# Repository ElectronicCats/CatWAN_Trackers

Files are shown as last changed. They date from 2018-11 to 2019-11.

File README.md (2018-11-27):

# LoRa CatTrack Zero

Electronic Cats invests time and resources providing this open source design, please support Electronic Cats and open-source hardware by purchasing products from Electronic Cats!

Designed by Electronic Cats.

Hardware released under an CERN Open Hardware Licence v1.2. See the LICENSE_HARDWARE file for more information.

Electronic Cats is a registered trademark, please do not use if you sell these PCBs.

26 Nov 2018

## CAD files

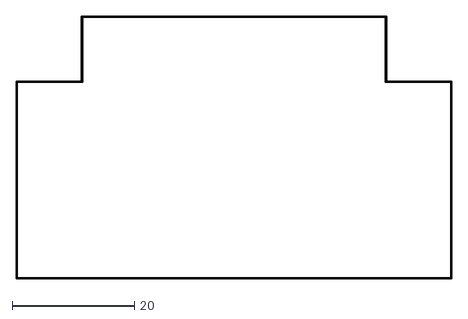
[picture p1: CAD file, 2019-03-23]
Hardware/gps_minimo/gps_vehicular-Edge_Cuts.dxf
71.3 x 43.1

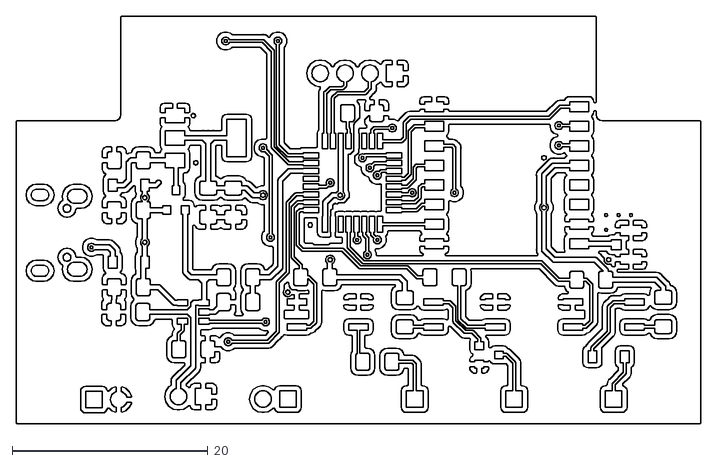
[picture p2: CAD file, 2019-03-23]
Hardware/gps_minimo/gps_vehicular-F_Cu.dxf
69.9 x 41.6

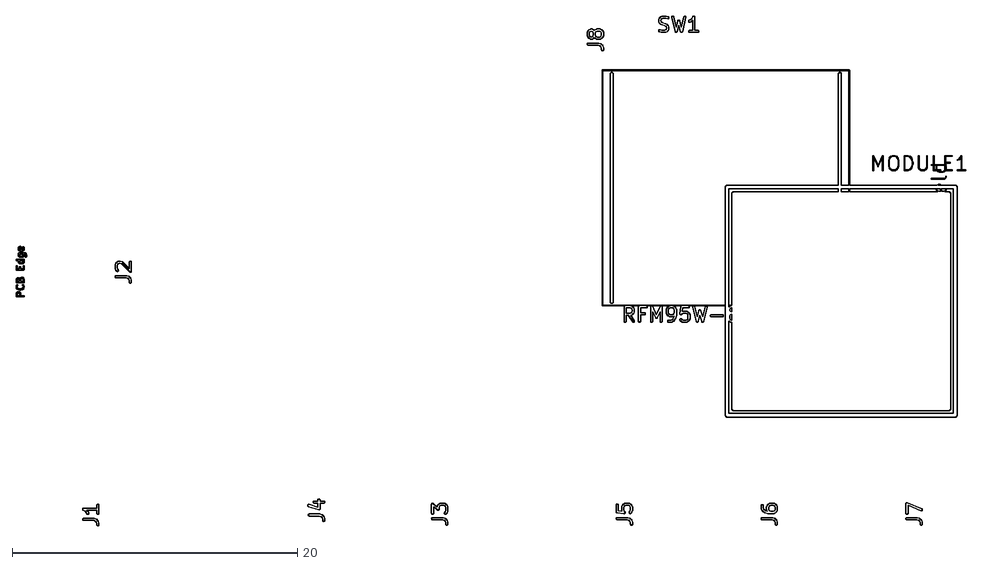
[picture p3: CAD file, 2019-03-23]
Hardware/gps_minimo/gps_vehicular-Dwgs_User.dxf
66.6 x 35.8

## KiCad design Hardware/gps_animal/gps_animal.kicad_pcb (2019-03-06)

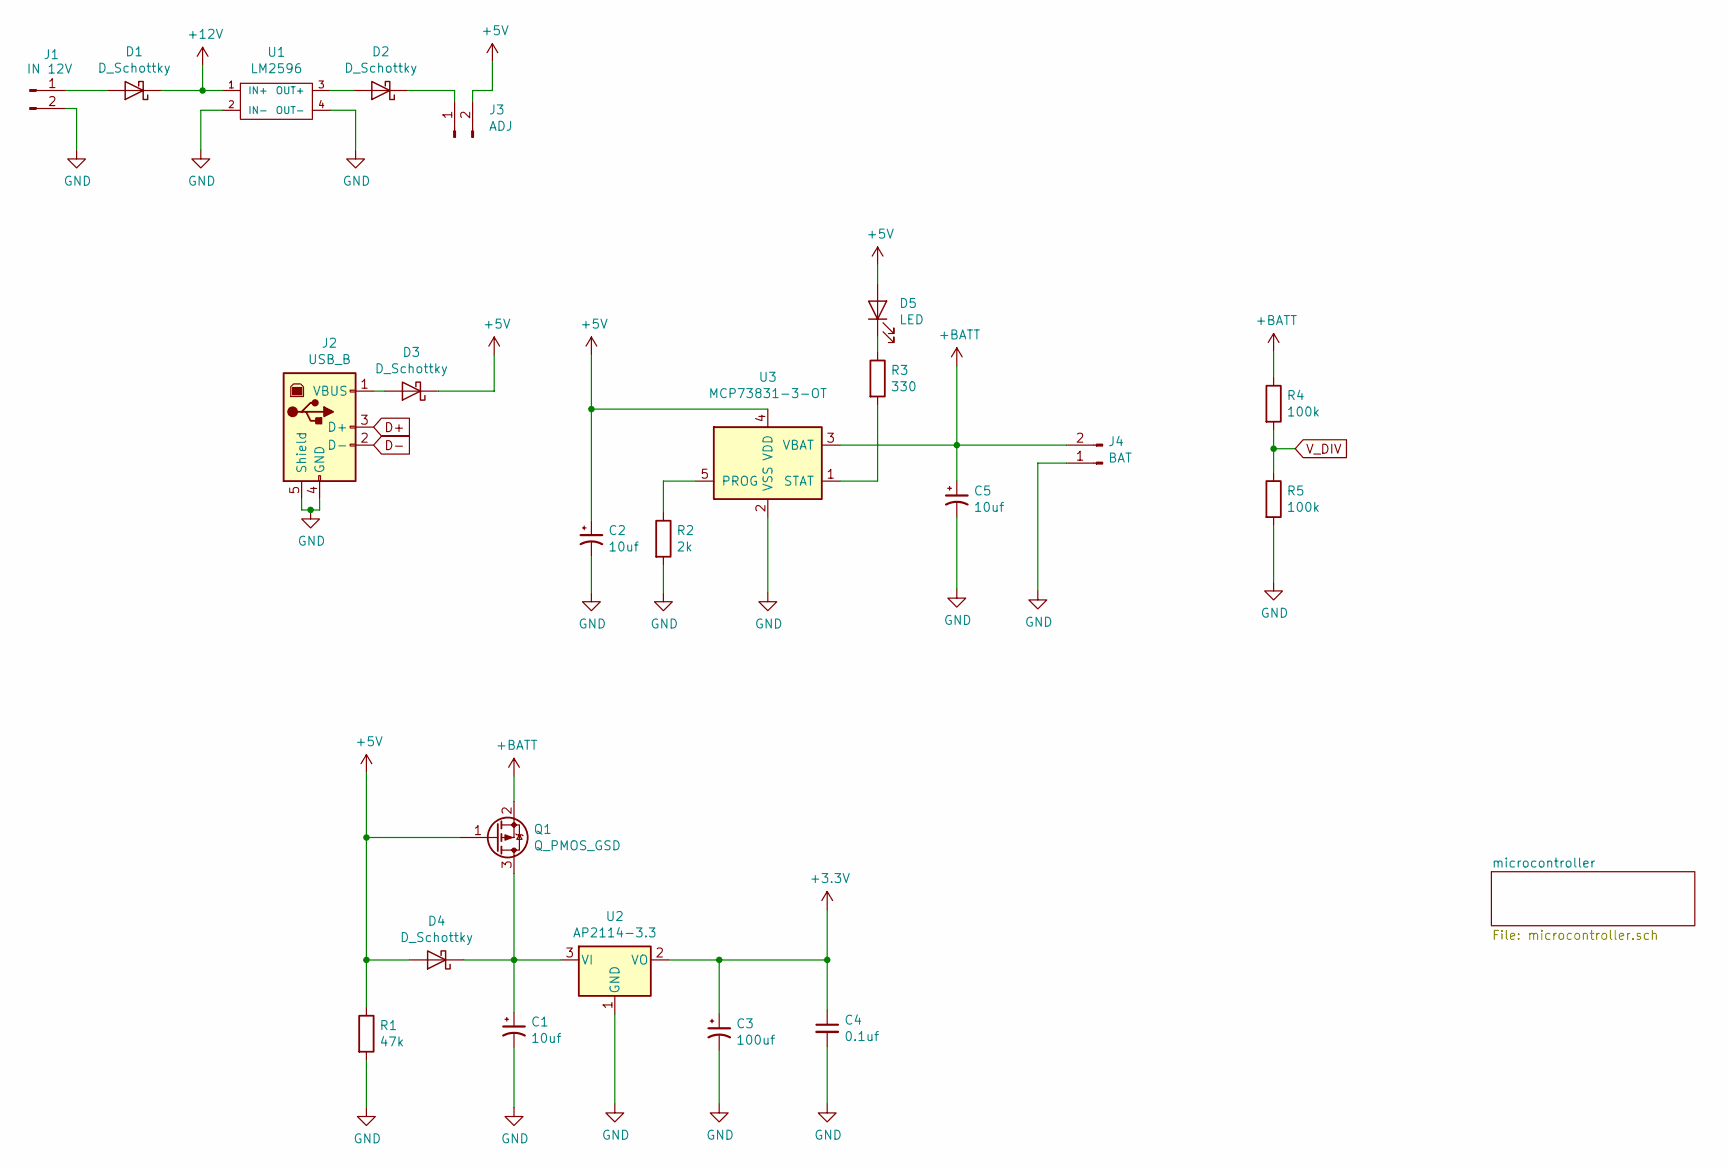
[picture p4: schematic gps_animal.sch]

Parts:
C1, C2, C5: 10uf; C_1206_3216Metric_Pad1.42x1.75mm_HandSolder
C3: 100uf; C_1206_3216Metric_Pad1.42x1.75mm_HandSolder
C4: 0.1uf; C_1206_3216Metric_Pad1.42x1.75mm_HandSolder
D1, D2, D3, D4: D_Schottky; D_SOD-123
D5: LED; LED_1206_3216Metric_Pad1.42x1.75mm_HandSolder
J1: IN 12V; PinHeader_1x02_P2.54mm_Vertical
J2: USB_B; USB_Micro-B_Wuerth_629105150521
J3: ADJ; PinHeader_1x02_P2.54mm_Vertical
J4: BAT; PinHeader_1x02_P2.54mm_Vertical
Q1: Q_PMOS_GSD; SOT-23
R1: 47k; R_1206_3216Metric_Pad1.42x1.75mm_HandSolder
R2: 2k; R_1206_3216Metric_Pad1.42x1.75mm_HandSolder
R3: 330; R_1206_3216Metric_Pad1.42x1.75mm_HandSolder
R4, R5: 100k; R_1206_3216Metric_Pad1.42x1.75mm_HandSolder
U1: LM2596; LM2596DC-DC
U2: AP2114-3.3; SOT-223-3_TabPin2
U3: MCP73831-3-OT; SOT-23-5

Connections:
+3V3: C3.1, C4.1, U2.2 (VO); also elsewhere on the board
+5V: C2.1, D3.1 (K), D4.2 (A), D5.2 (A), J3.2, Q1.1 (G), R1.1, U3.4 (VDD)
+12V: D1.1 (K), U1.1 (IN+); also elsewhere on the board
+BATT: C5.1, J4.2, Q1.2 (S), R4.1, U3.3 (VBAT)
D+: J2.3 (D+); also elsewhere on the board
D-: J2.2 (D-); also elsewhere on the board
GND: C1.2, C2.2, C3.2, C4.2, C5.2, J1.2, J2.4 (GND), J2.5 (Shield), J4.1, R1.2, R2.2, R5.2, U1.2 (IN-), U1.4 (OUT-), U2.1 (GND), U3.2 (VSS); also elsewhere on the board
unnamed: C1.1, D4.1 (K), Q1.3 (D), U2.3 (VI)
unnamed: D1.2 (A), J1.1
unnamed: D2.1 (K), J3.1
unnamed: D2.2 (A), U1.3 (OUT+)
unnamed: D3.2 (A), J2.1 (VBUS)
unnamed: D5.1 (K), R3.1
unnamed: R2.1, U3.5 (PROG)
unnamed: R3.2, U3.1 (STAT)
V_DIV: R4.2, R5.1

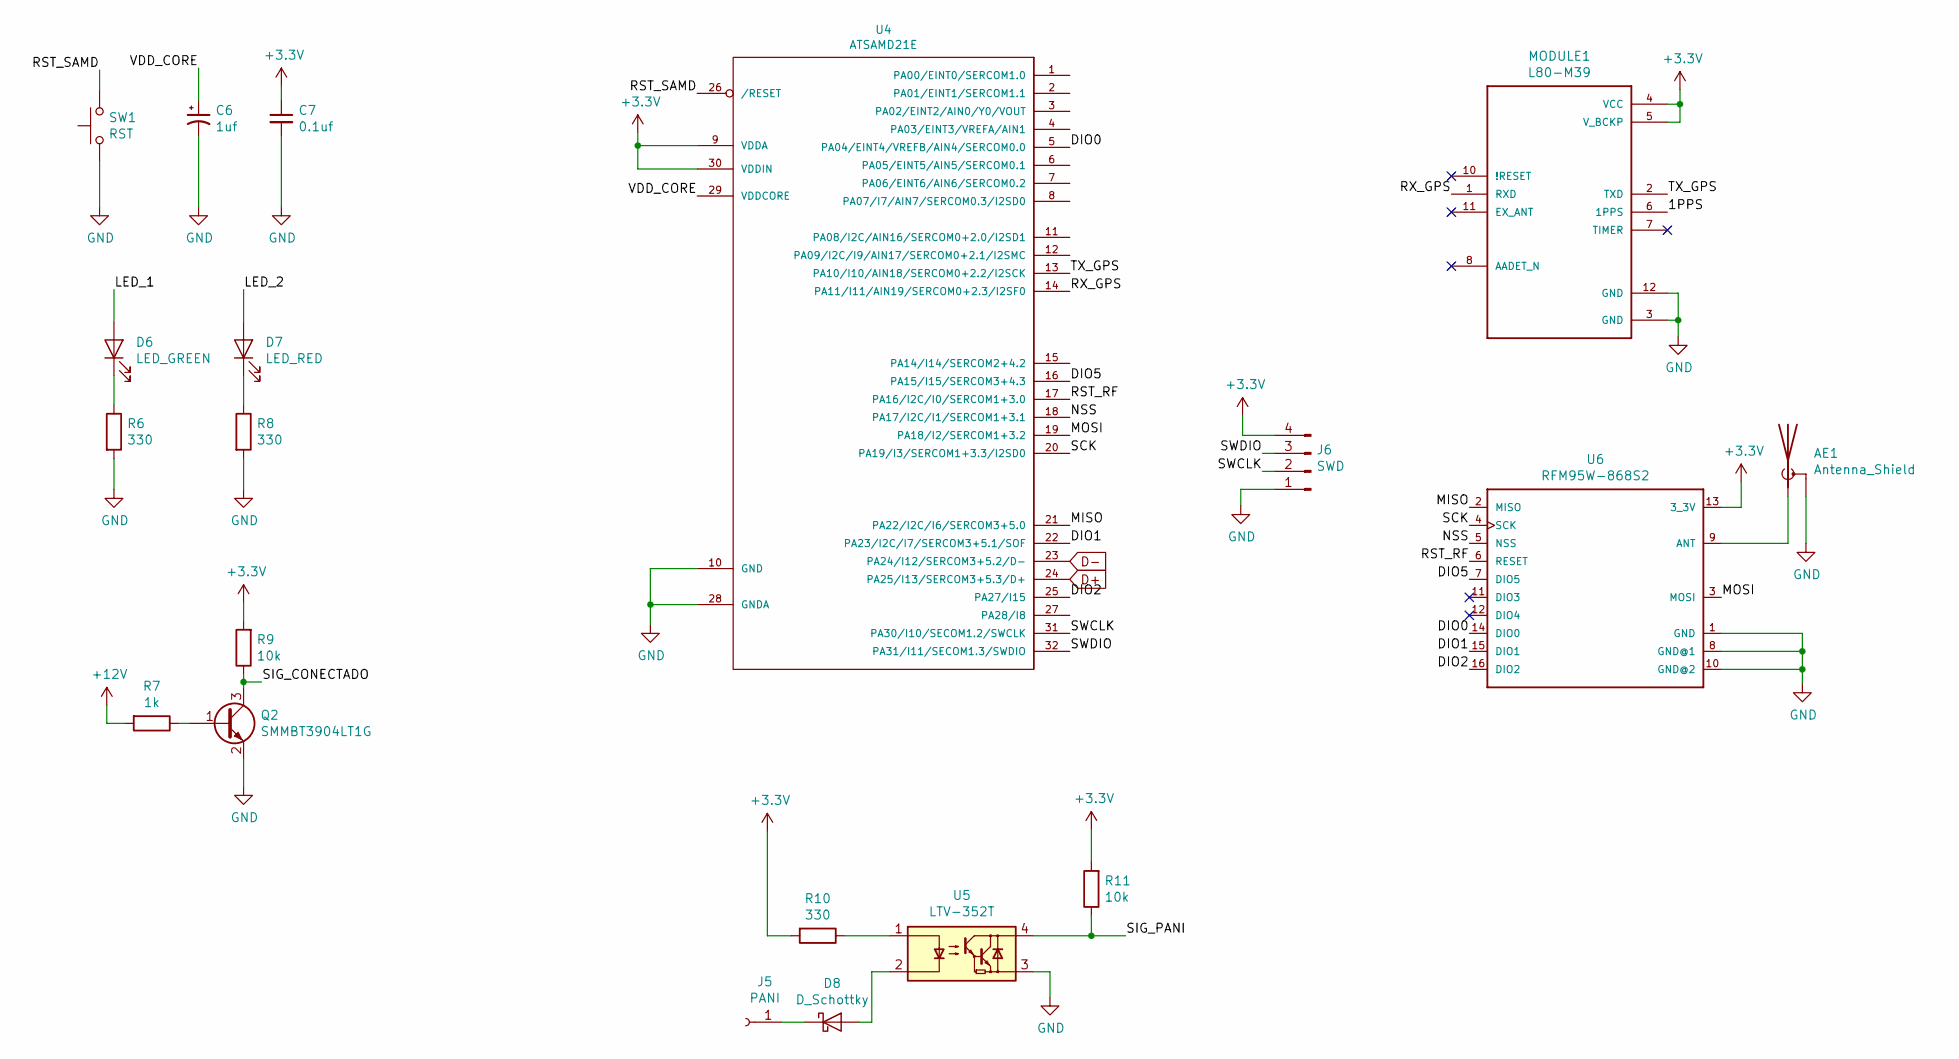
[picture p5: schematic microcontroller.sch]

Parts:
AE1: Antenna_Shield; MOLEX_1661
C6: 1uf; C_1206_3216Metric_Pad1.42x1.75mm_HandSolder
C7: 0.1uf; C_1206_3216Metric_Pad1.42x1.75mm_HandSolder
D6: LED_GREEN; LED_1206_3216Metric_Castellated
D7: LED_RED; LED_1206_3216Metric_Castellated
D8: D_Schottky; D_SOD-123
J5: PANI; PinHeader_1x01_P2.54mm_Vertical
J6: SWD; PinHeader_1x04_P2.54mm_Vertical
MODULE1: L80-M39; QUECTEL_L80-M39
Q2: SMMBT3904LT1G; SOT-23
R6, R8, R10: 330; R_1206_3216Metric_Pad1.42x1.75mm_HandSolder
R7: 1k; R_1206_3216Metric_Pad1.42x1.75mm_HandSolder
R9, R11: 10k; R_1206_3216Metric_Pad1.42x1.75mm_HandSolder
SW1: RST; SW_SPST_TL3342
U4: ATSAMD21E; TQFP-32_7x7mm_P0.8mm
U5: LTV-352T; SO-4_4.4x3.6mm_P2.54mm
U6: RFM95W-868S2; RFM95W

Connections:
+3V3: C7.1, J6.4, MODULE1.4 (VCC), MODULE1.5 (V_BCKP), R9.2, R10.2, R11.2, U4.9 (VDDA), U4.30 (VDDIN), U6.13 (3_3V); also elsewhere on the board
+12V: R7.2; also elsewhere on the board
/microcontroller/1PPS: MODULE1.6 (1PPS)
/microcontroller/DIO0: U4.5 (PA04/EINT4/VREFB/AIN4/SERCOM0.0), U6.14 (DIO0)
/microcontroller/DIO1: U4.22 (PA23/I2C/I7/SERCOM3+5.1/SOF), U6.15 (DIO1)
/microcontroller/DIO2: U4.25 (PA27/I15), U6.16 (DIO2)
/microcontroller/DIO5: U4.16 (PA15/I15/SERCOM3+4.3), U6.7 (DIO5)
/microcontroller/LED_1: D6.2 (A)
/microcontroller/LED_2: D7.2 (A)
/microcontroller/MISO: U4.21 (PA22/I2C/I6/SERCOM3+5.0), U6.2 (MISO)
/microcontroller/MOSI: U4.19 (PA18/I2/SERCOM1+3.2), U6.3 (MOSI)
/microcontroller/NSS: U4.18 (PA17/I2C/I1/SERCOM1+3.1), U6.5 (NSS)
/microcontroller/RST_RF: U4.17 (PA16/I2C/I0/SERCOM1+3.0), U6.6 (RESET)
/microcontroller/RST_SAMD: SW1.2, U4.26 (/RESET)
/microcontroller/RX_GPS: MODULE1.1 (RXD), U4.14 (PA11/I11/AIN19/SERCOM0+2.3/I2SF0)
/microcontroller/SCK: U4.20 (PA19/I3/SERCOM1+3.3/I2SD0), U6.4 (SCK)
/microcontroller/SIG_CONECTADO: Q2.3 (C), R9.1
/microcontroller/SIG_PANI: R11.1, U5.4
/microcontroller/SWCLK: J6.2, U4.31 (PA30/I10/SECOM1.2/SWCLK)
/microcontroller/SWDIO: J6.3, U4.32 (PA31/I11/SECOM1.3/SWDIO)
/microcontroller/TX_GPS: MODULE1.2 (TXD), U4.13 (PA10/I10/AIN18/SERCOM0+2.2/I2SCK)
/microcontroller/VDD_CORE: C6.1, U4.29 (VDDCORE)
D+: U4.24 (PA25/I13/SERCOM3+5.3/D+); also elsewhere on the board
D-: U4.23 (PA24/I12/SERCOM3+5.2/D-); also elsewhere on the board
GND: AE1.2 (Shield), C6.2, C7.2, J6.1, MODULE1.3 (GND), MODULE1.12 (GND), Q2.2 (E), R6.2, R8.2, SW1.1, U4.10 (GND), U4.28 (GNDA), U5.3, U6.1 (GND), U6.8 (GND@1), U6.10 (GND@2); also elsewhere on the board
unnamed: AE1.1 (A), U6.9 (ANT)
unnamed: D6.1 (K), R6.1
unnamed: D7.1 (K), R8.1
unnamed: D8.1 (K), J5.1
unnamed: D8.2 (A), U5.2
unnamed: Q2.1 (B), R7.1
unnamed: R10.1, U5.1

Board: 2 copper layers, 43 parts (0 on the bottom side), 40 nets, no tracks yet.

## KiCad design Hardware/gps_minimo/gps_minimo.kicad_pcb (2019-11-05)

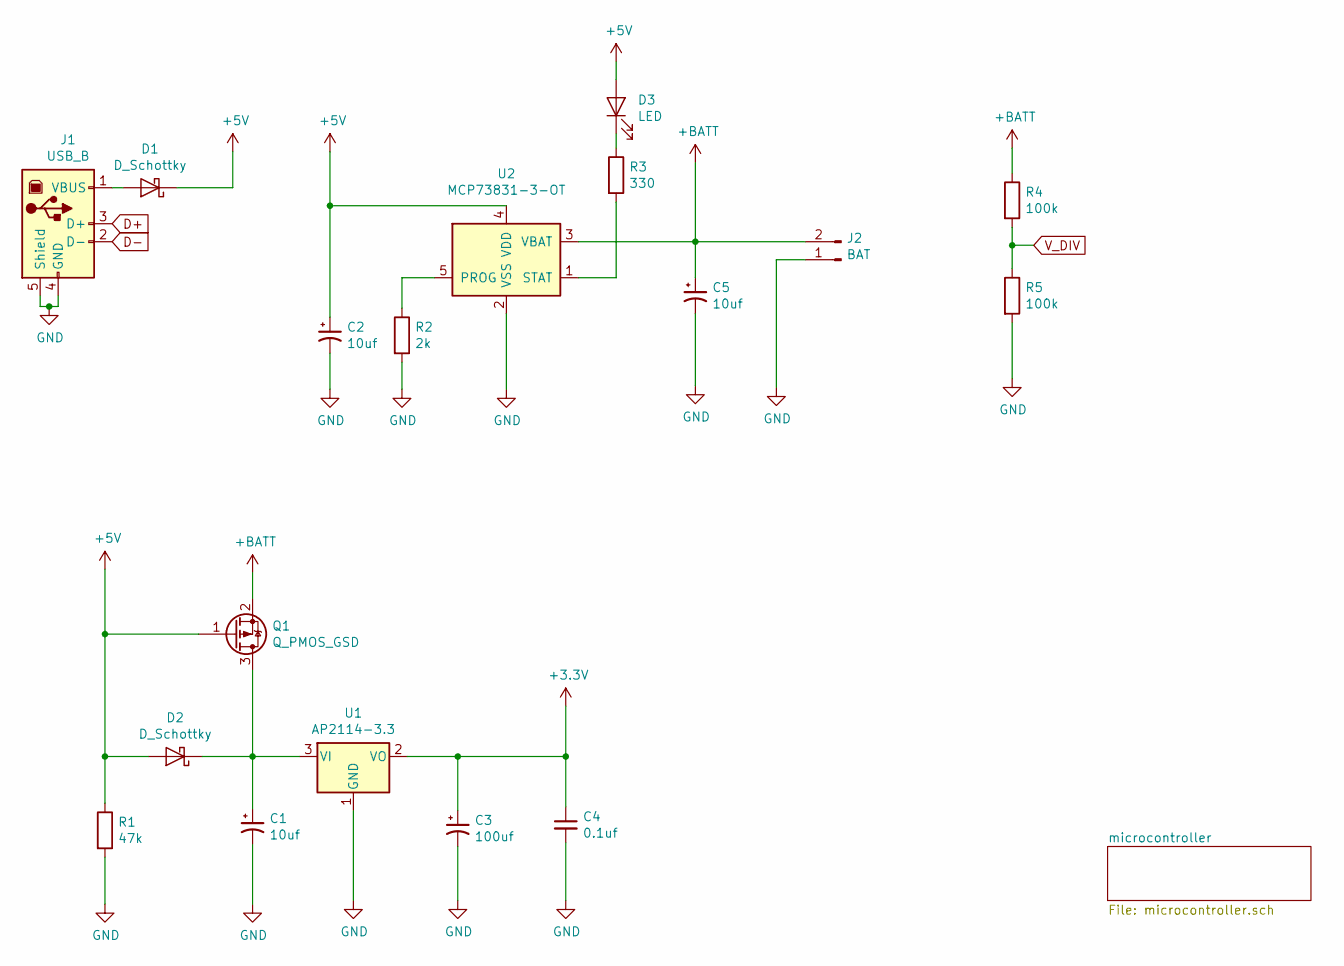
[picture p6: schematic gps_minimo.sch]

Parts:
C1, C2, C5: 10uf; C_1206_3216Metric_Pad1.42x1.75mm_HandSolder
C3: 100uf; C_1206_3216Metric_Pad1.42x1.75mm_HandSolder
C4: 0.1uf; C_1206_3216Metric_Pad1.42x1.75mm_HandSolder
D1, D2: D_Schottky; D_SOD-123
D3: LED; LED_1206_3216Metric_Pad1.42x1.75mm_HandSolder
J1: USB_B; USB_Micro-B_Wuerth_629105150521
J2: BAT; PinHeader_1x02_P2.54mm_Vertical
Q1: Q_PMOS_GSD; SOT-23
R1: 47k; R_1206_3216Metric_Pad1.42x1.75mm_HandSolder
R2: 2k; R_1206_3216Metric_Pad1.42x1.75mm_HandSolder
R3: 330; R_1206_3216Metric_Pad1.42x1.75mm_HandSolder
R4, R5: 100k; R_1206_3216Metric_Pad1.42x1.75mm_HandSolder
U1: AP2114-3.3; SOT-223-3_TabPin2
U2: MCP73831-3-OT; SOT-23-5

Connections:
+3V3: C3.1, C4.1, U1.2 (VO); also elsewhere on the board
+5V: C2.1, D1.1 (K), D2.2 (A), D3.2 (A), Q1.1 (G), R1.1, U2.4 (VDD)
+BATT: C5.1, J2.2, Q1.2 (S), R4.1, U2.3 (VBAT)
D+: J1.3 (D+); also elsewhere on the board
D-: J1.2 (D-); also elsewhere on the board
GND: C1.2, C2.2, C3.2, C4.2, C5.2, J1.4 (GND), J1.5 (Shield), J2.1, R1.2, R2.2, R5.2, U1.1 (GND), U2.2 (VSS); also elsewhere on the board
unnamed: C1.1, D2.1 (K), Q1.3 (D), U1.3 (VI)
unnamed: D1.2 (A), J1.1 (VBUS)
unnamed: D3.1 (K), R3.1
unnamed: R2.1, U2.5 (PROG)
unnamed: R3.2, U2.1 (STAT)
V_DIV: R4.2, R5.1; also elsewhere on the board

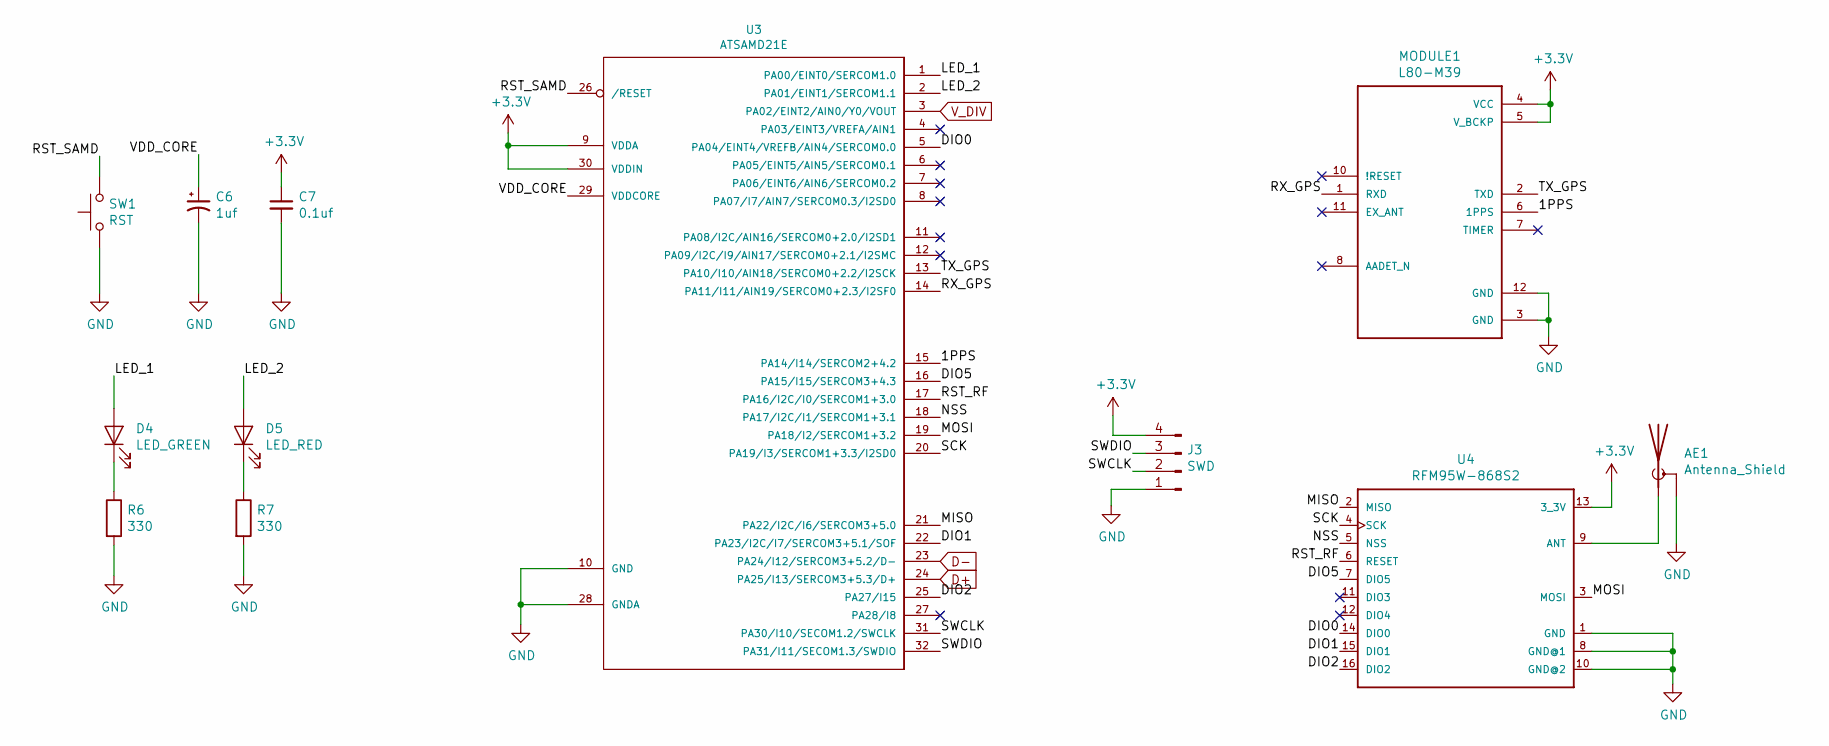
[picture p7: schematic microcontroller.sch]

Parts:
AE1: Antenna_Shield; MOLEX_1661
C6: 1uf; C_1206_3216Metric_Pad1.42x1.75mm_HandSolder
C7: 0.1uf; C_1206_3216Metric_Pad1.42x1.75mm_HandSolder
D4: LED_GREEN; LED_1206_3216Metric_Castellated
D5: LED_RED; LED_1206_3216Metric_Castellated
J3: SWD; PinHeader_1x04_P2.54mm_Vertical
MODULE1: L80-M39; QUECTEL_L80-M39
R6, R7: 330; R_1206_3216Metric_Pad1.42x1.75mm_HandSolder
SW1: RST; SW_SPST_TL3342
U3: ATSAMD21E; TQFP-32_7x7mm_P0.8mm
U4: RFM95W-868S2; RFM95W

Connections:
+3V3: C7.1, J3.4, MODULE1.4 (VCC), MODULE1.5 (V_BCKP), U3.9 (VDDA), U3.30 (VDDIN), U4.13 (3_3V); also elsewhere on the board
/microcontroller/1PPS: MODULE1.6 (1PPS), U3.15 (PA14/I14/SERCOM2+4.2)
/microcontroller/DIO0: U3.5 (PA04/EINT4/VREFB/AIN4/SERCOM0.0), U4.14 (DIO0)
/microcontroller/DIO1: U3.22 (PA23/I2C/I7/SERCOM3+5.1/SOF), U4.15 (DIO1)
/microcontroller/DIO2: U3.25 (PA27/I15), U4.16 (DIO2)
/microcontroller/DIO5: U3.16 (PA15/I15/SERCOM3+4.3), U4.7 (DIO5)
/microcontroller/LED_1: D4.2 (A), U3.1 (PA00/EINT0/SERCOM1.0)
/microcontroller/LED_2: D5.2 (A), U3.2 (PA01/EINT1/SERCOM1.1)
/microcontroller/MISO: U3.21 (PA22/I2C/I6/SERCOM3+5.0), U4.2 (MISO)
/microcontroller/MOSI: U3.19 (PA18/I2/SERCOM1+3.2), U4.3 (MOSI)
/microcontroller/NSS: U3.18 (PA17/I2C/I1/SERCOM1+3.1), U4.5 (NSS)
/microcontroller/RST_RF: U3.17 (PA16/I2C/I0/SERCOM1+3.0), U4.6 (RESET)
/microcontroller/RST_SAMD: SW1.2, U3.26 (/RESET)
/microcontroller/RX_GPS: MODULE1.1 (RXD), U3.14 (PA11/I11/AIN19/SERCOM0+2.3/I2SF0)
/microcontroller/SCK: U3.20 (PA19/I3/SERCOM1+3.3/I2SD0), U4.4 (SCK)
/microcontroller/SWCLK: J3.2, U3.31 (PA30/I10/SECOM1.2/SWCLK)
/microcontroller/SWDIO: J3.3, U3.32 (PA31/I11/SECOM1.3/SWDIO)
/microcontroller/TX_GPS: MODULE1.2 (TXD), U3.13 (PA10/I10/AIN18/SERCOM0+2.2/I2SCK)
/microcontroller/VDD_CORE: C6.1, U3.29 (VDDCORE)
D+: U3.24 (PA25/I13/SERCOM3+5.3/D+); also elsewhere on the board
D-: U3.23 (PA24/I12/SERCOM3+5.2/D-); also elsewhere on the board
GND: AE1.2 (Shield), C6.2, C7.2, J3.1, MODULE1.3 (GND), MODULE1.12 (GND), R6.2, R7.2, SW1.1, U3.10 (GND), U3.28 (GNDA), U4.1 (GND), U4.8 (GND@1), U4.10 (GND@2); also elsewhere on the board
unnamed: AE1.1 (A), U4.9 (ANT)
unnamed: D4.1 (K), R6.1
unnamed: D5.1 (K), R7.1
V_DIV: U3.3 (PA02/EINT2/AIN0/Y0/VOUT); also elsewhere on the board

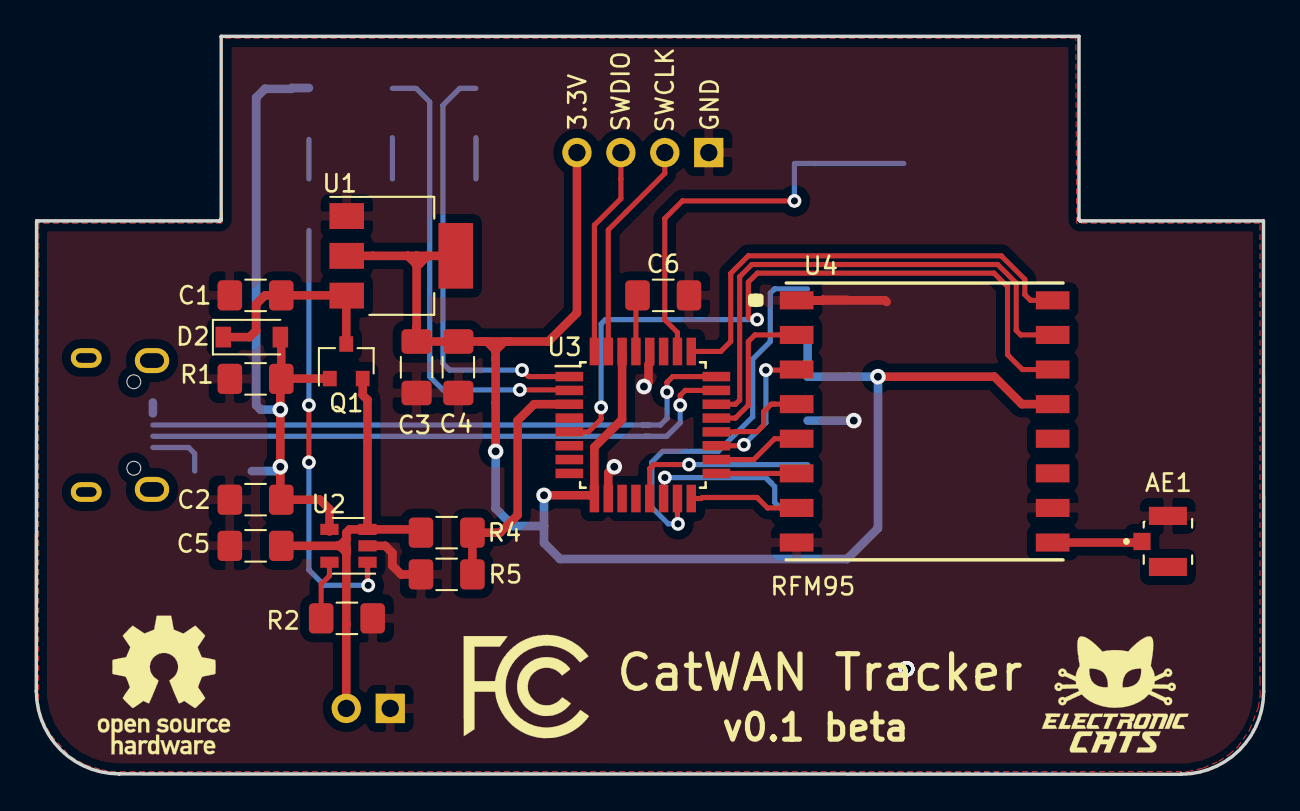
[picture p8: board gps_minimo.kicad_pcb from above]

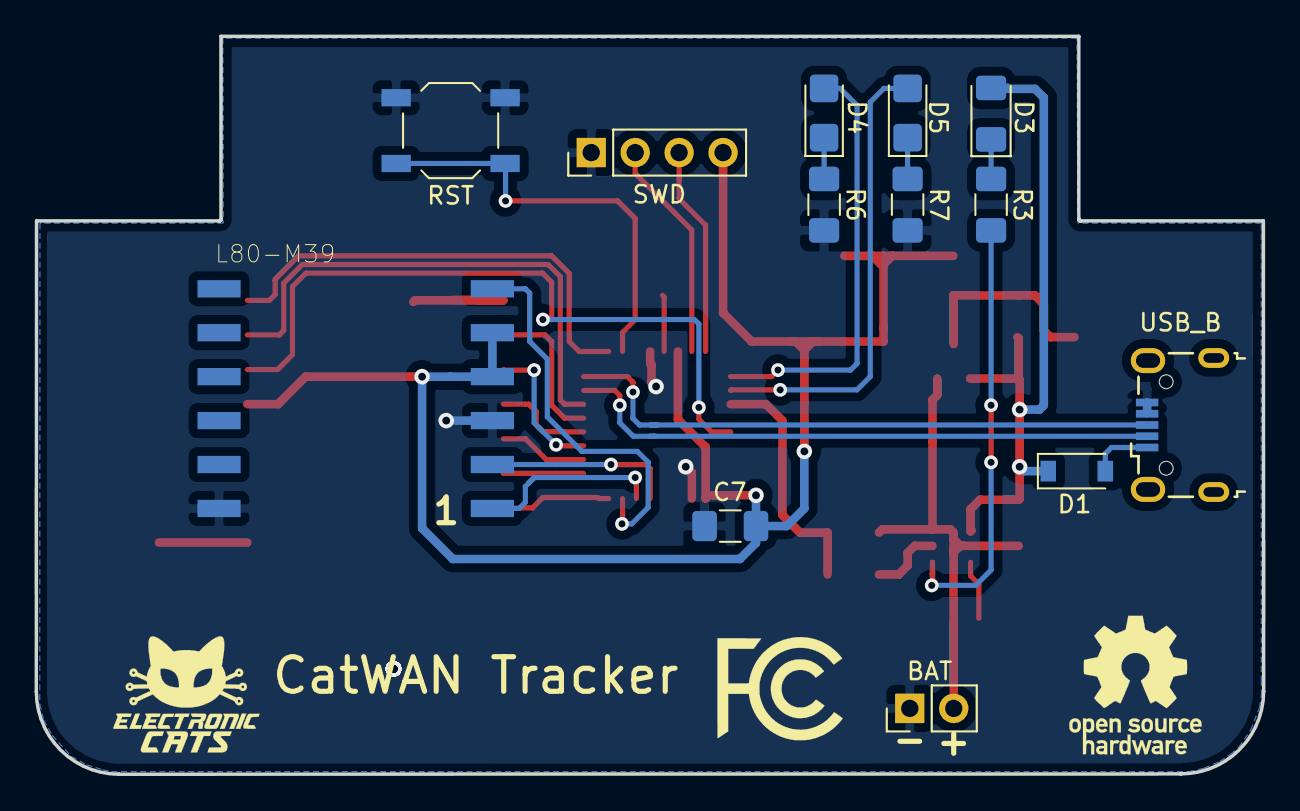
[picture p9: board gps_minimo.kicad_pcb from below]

Board: 2 copper layers, 71.0 x 42.7 mm, 30 parts (13 on the bottom side), 33 nets.

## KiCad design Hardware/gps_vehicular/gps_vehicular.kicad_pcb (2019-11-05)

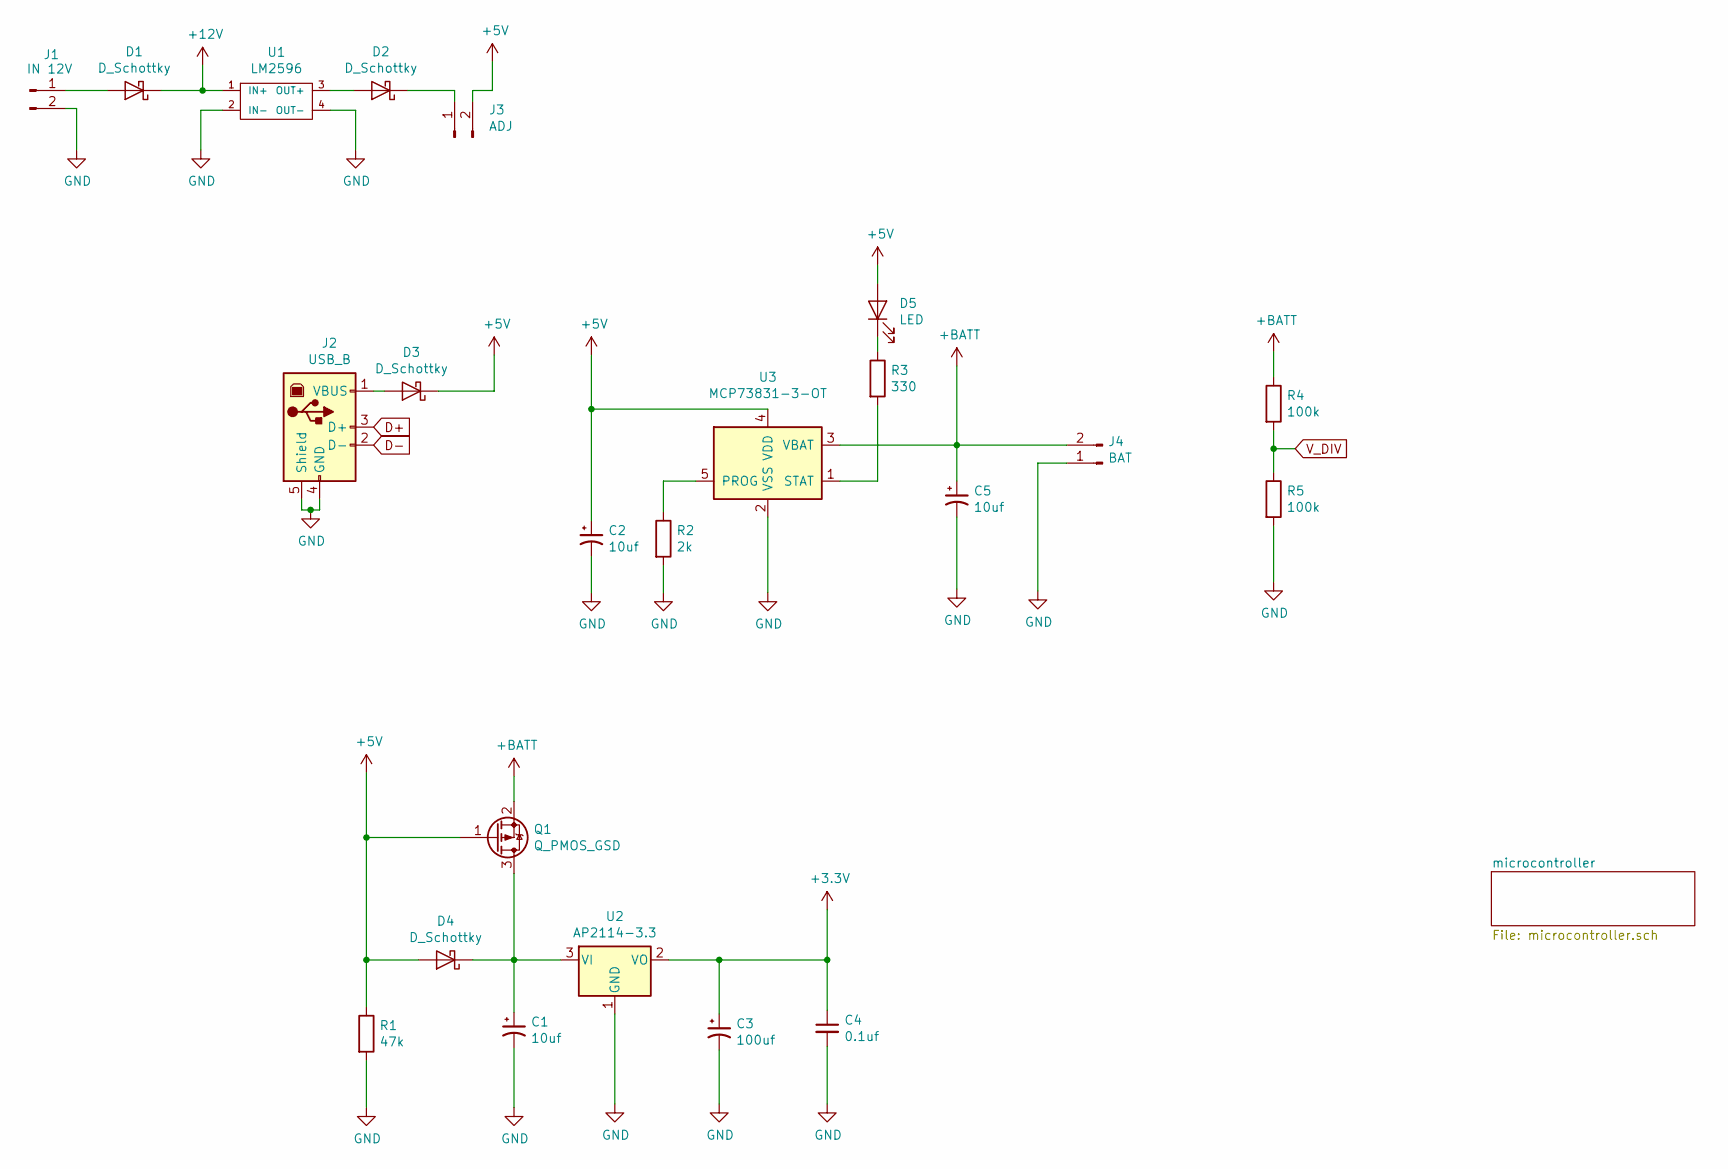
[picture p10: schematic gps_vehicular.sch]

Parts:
C1, C2, C5: 10uf; C_1206_3216Metric_Pad1.42x1.75mm_HandSolder
C3: 100uf; C_1206_3216Metric_Pad1.42x1.75mm_HandSolder
C4: 0.1uf; C_1206_3216Metric_Pad1.42x1.75mm_HandSolder
D1, D2, D3, D4: D_Schottky; D_SOD-123
D5: LED; LED_1206_3216Metric_Pad1.42x1.75mm_HandSolder
J1: IN 12V; PinHeader_1x02_P2.54mm_Vertical
J2: USB_B; USB_Micro-B_Wuerth_629105150521
J3: ADJ; PinHeader_1x02_P2.54mm_Vertical
J4: BAT; PinHeader_1x02_P2.54mm_Vertical
Q1: Q_PMOS_GSD; SOT-23
R1: 47k; R_1206_3216Metric_Pad1.42x1.75mm_HandSolder
R2: 2k; R_1206_3216Metric_Pad1.42x1.75mm_HandSolder
R3: 330; R_1206_3216Metric_Pad1.42x1.75mm_HandSolder
R4, R5: 100k; R_1206_3216Metric_Pad1.42x1.75mm_HandSolder
U1: LM2596; LM2596DC-DC
U2: AP2114-3.3; SOT-223-3_TabPin2
U3: MCP73831-3-OT; SOT-23-5

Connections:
+3V3: C3.1, C4.1, U2.2 (VO); also elsewhere on the board
+5V: C2.1, D3.1 (K), D4.2 (A), D5.2 (A), J3.2, Q1.1 (G), R1.1, U3.4 (VDD)
+12V: D1.1 (K), U1.1 (IN+); also elsewhere on the board
+BATT: C5.1, J4.2, Q1.2 (S), R4.1, U3.3 (VBAT)
D+: J2.3 (D+); also elsewhere on the board
D-: J2.2 (D-); also elsewhere on the board
GND: C1.2, C2.2, C3.2, C4.2, C5.2, J1.2, J2.4 (GND), J2.5 (Shield), J4.1, R1.2, R2.2, R5.2, U1.2 (IN-), U1.4 (OUT-), U2.1 (GND), U3.2 (VSS); also elsewhere on the board
unnamed: C1.1, D4.1 (K), Q1.3 (D), U2.3 (VI)
unnamed: D1.2 (A), J1.1
unnamed: D2.1 (K), J3.1
unnamed: D2.2 (A), U1.3 (OUT+)
unnamed: D3.2 (A), J2.1 (VBUS)
unnamed: D5.1 (K), R3.1
unnamed: R2.1, U3.5 (PROG)
unnamed: R3.2, U3.1 (STAT)
V_DIV: R4.2, R5.1; also elsewhere on the board

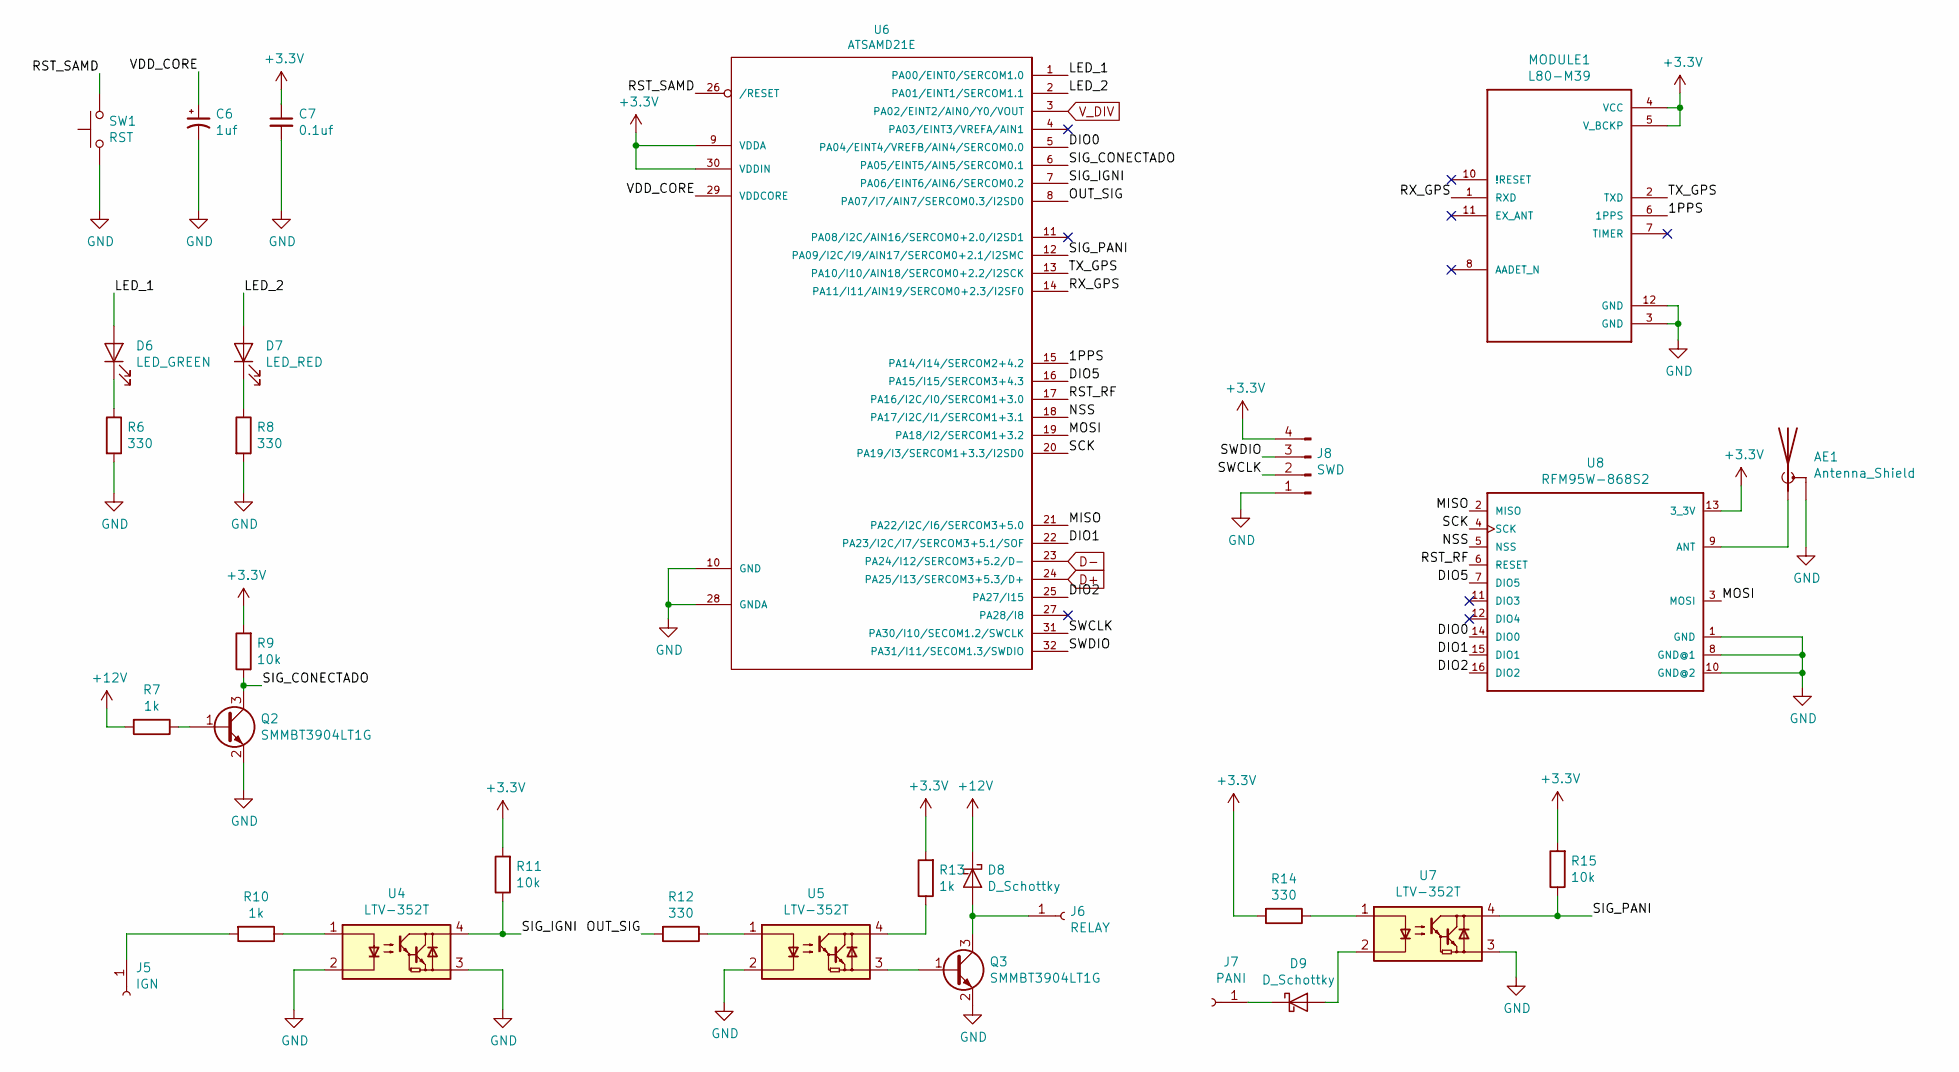
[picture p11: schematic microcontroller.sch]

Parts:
AE1: Antenna_Shield; MOLEX_1661
C6: 1uf; C_1206_3216Metric_Pad1.42x1.75mm_HandSolder
C7: 0.1uf; C_1206_3216Metric_Pad1.42x1.75mm_HandSolder
D6: LED_GREEN; LED_1206_3216Metric_Castellated
D7: LED_RED; LED_1206_3216Metric_Castellated
D8, D9: D_Schottky; D_SOD-123
J5: IGN; PinHeader_1x01_P2.54mm_Vertical
J6: RELAY; PinHeader_1x01_P2.54mm_Vertical
J7: PANI; PinHeader_1x01_P2.54mm_Vertical
J8: SWD; PinHeader_1x04_P2.54mm_Vertical
MODULE1: L80-M39; QUECTEL_L80-M39
Q2, Q3: SMMBT3904LT1G; SOT-23
R6, R8, R12, R14: 330; R_1206_3216Metric_Pad1.42x1.75mm_HandSolder
R7, R10, R13: 1k; R_1206_3216Metric_Pad1.42x1.75mm_HandSolder
R9, R11, R15: 10k; R_1206_3216Metric_Pad1.42x1.75mm_HandSolder
SW1: RST; SW_SPST_TL3342
U4, U5, U7: LTV-352T; SO-4_4.4x3.6mm_P2.54mm
U6: ATSAMD21E; TQFP-32_7x7mm_P0.8mm
U8: RFM95W-868S2; RFM95W

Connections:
+3V3: C7.1, J8.4, MODULE1.4 (VCC), MODULE1.5 (V_BCKP), R9.2, R11.2, R13.2, R14.2, R15.2, U6.9 (VDDA), U6.30 (VDDIN), U8.13 (3_3V); also elsewhere on the board
+12V: D8.1 (K), R7.2; also elsewhere on the board
/microcontroller/1PPS: MODULE1.6 (1PPS), U6.15 (PA14/I14/SERCOM2+4.2)
/microcontroller/DIO0: U6.5 (PA04/EINT4/VREFB/AIN4/SERCOM0.0), U8.14 (DIO0)
/microcontroller/DIO1: U6.22 (PA23/I2C/I7/SERCOM3+5.1/SOF), U8.15 (DIO1)
/microcontroller/DIO2: U6.25 (PA27/I15), U8.16 (DIO2)
/microcontroller/DIO5: U6.16 (PA15/I15/SERCOM3+4.3), U8.7 (DIO5)
/microcontroller/LED_1: D6.2 (A), U6.1 (PA00/EINT0/SERCOM1.0)
/microcontroller/LED_2: D7.2 (A), U6.2 (PA01/EINT1/SERCOM1.1)
/microcontroller/MISO: U6.21 (PA22/I2C/I6/SERCOM3+5.0), U8.2 (MISO)
/microcontroller/MOSI: U6.19 (PA18/I2/SERCOM1+3.2), U8.3 (MOSI)
/microcontroller/NSS: U6.18 (PA17/I2C/I1/SERCOM1+3.1), U8.5 (NSS)
/microcontroller/OUT_SIG: R12.2, U6.8 (PA07/I7/AIN7/SERCOM0.3/I2SD0)
/microcontroller/RST_RF: U6.17 (PA16/I2C/I0/SERCOM1+3.0), U8.6 (RESET)
/microcontroller/RST_SAMD: SW1.2, U6.26 (/RESET)
/microcontroller/RX_GPS: MODULE1.1 (RXD), U6.14 (PA11/I11/AIN19/SERCOM0+2.3/I2SF0)
/microcontroller/SCK: U6.20 (PA19/I3/SERCOM1+3.3/I2SD0), U8.4 (SCK)
/microcontroller/SIG_CONECTADO: Q2.3 (C), R9.1, U6.6 (PA05/EINT5/AIN5/SERCOM0.1)
/microcontroller/SIG_IGNI: R11.1, U4.4, U6.7 (PA06/EINT6/AIN6/SERCOM0.2)
/microcontroller/SIG_PANI: R15.1, U6.12 (PA09/I2C/I9/AIN17/SERCOM0+2.1/I2SMC), U7.4
/microcontroller/SWCLK: J8.2, U6.31 (PA30/I10/SECOM1.2/SWCLK)
/microcontroller/SWDIO: J8.3, U6.32 (PA31/I11/SECOM1.3/SWDIO)
/microcontroller/TX_GPS: MODULE1.2 (TXD), U6.13 (PA10/I10/AIN18/SERCOM0+2.2/I2SCK)
/microcontroller/VDD_CORE: C6.1, U6.29 (VDDCORE)
D+: U6.24 (PA25/I13/SERCOM3+5.3/D+); also elsewhere on the board
D-: U6.23 (PA24/I12/SERCOM3+5.2/D-); also elsewhere on the board
GND: AE1.2 (Shield), C6.2, C7.2, J8.1, MODULE1.3 (GND), MODULE1.12 (GND), Q2.2 (E), Q3.2 (E), R6.2, R8.2, SW1.1, U4.2, U4.3, U5.2, U6.10 (GND), U6.28 (GNDA), U7.3, U8.1 (GND), U8.8 (GND@1), U8.10 (GND@2); also elsewhere on the board
unnamed: AE1.1 (A), U8.9 (ANT)
unnamed: D6.1 (K), R6.1
unnamed: D7.1 (K), R8.1
unnamed: D8.2 (A), J6.1, Q3.3 (C)
unnamed: D9.1 (K), J7.1
unnamed: D9.2 (A), U7.2
unnamed: J5.1, R10.2
unnamed: Q2.1 (B), R7.1
unnamed: Q3.1 (B), U5.3
unnamed: R10.1, U4.1
unnamed: R12.1, U5.1
unnamed: R13.1, U5.4
unnamed: R14.1, U7.1
V_DIV: U6.3 (PA02/EINT2/AIN0/Y0/VOUT); also elsewhere on the board

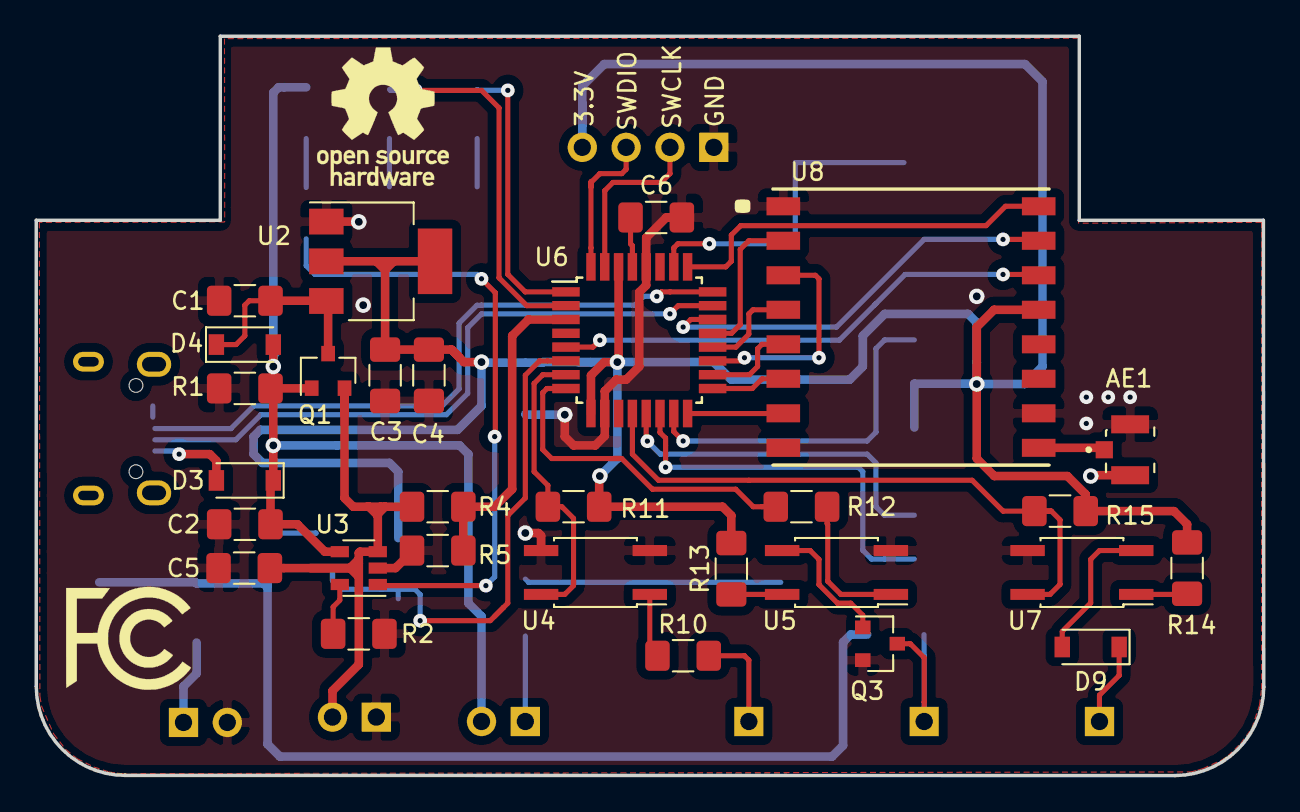
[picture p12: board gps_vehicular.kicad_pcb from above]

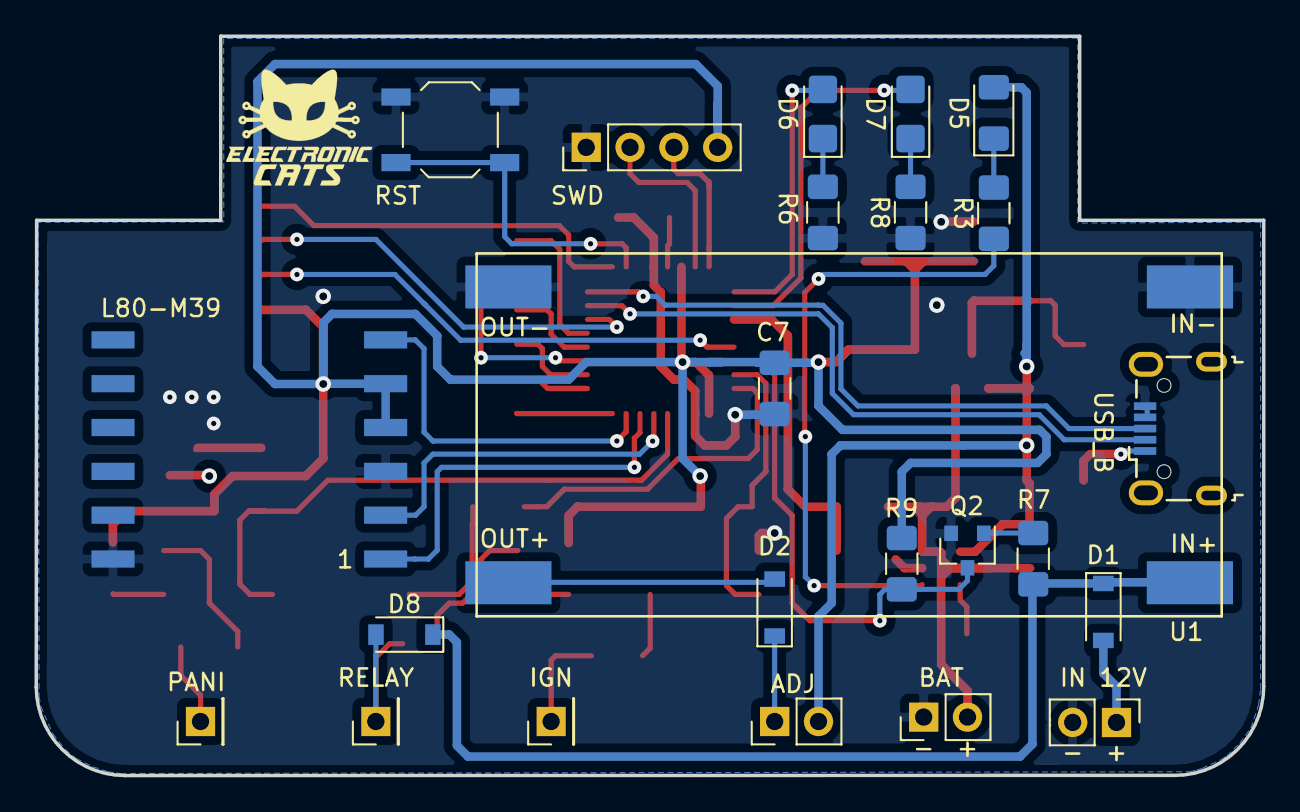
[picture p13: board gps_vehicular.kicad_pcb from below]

Board: 2 copper layers, 71.1 x 42.8 mm, 53 parts (24 on the bottom side), 51 nets.

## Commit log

2018-11-27 inicial schematic
    [lora minimo.sch]
2018-11-30 ACELEROMETER AND EPROOM
    [lora minimo.sch]
2018-12-07 MEMORY AND ACCELEROMETER UPDATE
    CHANGED BY A FLASH MEMORY OF 2 MB AND CHANGED BY ACCELEROMETER MODULE
    [lora minimo.sch]
2019-01-04 ADDED FOOTPRINTS
    ADDED FOOTPRINTS AND DID UPDATES
2019-01-04 Add PCB and netlist
    [lora minimo.kicad_pcb]
2019-01-04 connection update
    [lora minimo.sch]
2019-01-05 add netist and pcb
    [lora minimo.kicad_pcb, lora minimo.sch]
2019-01-31 PCB test
    pcb design and fingerprint reallocation
    [lora minimo.kicad_pcb, lora minimo.sch]
2019-03-23 add pcb gps vehicular and minimo
    [gps_minimo.kicad_pcb, gps_minimo.sch, gps_vehicular-Dwgs_User.dxf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]
2019-03-26 add logos gps minimo
    [gps_minimo.kicad_pcb]
2019-03-26 add logos
    [gps_minimo.kicad_pcb, gps_vehicular.kicad_pcb]
2019-03-29 Round off the corners and change screen printing gps_vehicular
    [gps_vehicular.kicad_pcb]
2019-03-29 Round off the corners and change screem printing gps_minimo
    [gps_minimo.kicad_pcb]
2019-03-29 add screen printing swd pins gps_vehicular
    [gps_vehicular.kicad_pcb]
2019-11-05 rename paths and rename
    [gps_animal.kicad_pcb, gps_animal.sch, gps_minimo.kicad_pcb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]
2019-11-05 schematic add
    [gps_minimo.sch, microcontroller.sch]
